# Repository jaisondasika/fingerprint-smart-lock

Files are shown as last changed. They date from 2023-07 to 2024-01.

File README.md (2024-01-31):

# Fingerprint Smart Lock

An Arduino based smart lock that also controls a LED strip. The LEDs react to you based on how close you are to the door and play a fun animation when unlocked! This also features anti-theft mode, which alarms if the door is broken open, and anti-pick mode, which vibrates the servo to make lockpicking impossible when detected!



This project has been tested on both the [TeensyLC](https://www.pjrc.com/store/teensylc.html) and [SeeduinoXIAO](https://www.seeedstudio.com/Seeeduino-XIAO-Arduino-Microcontroller-SAMD21-Cortex-M0+-p-4426.html) microcontrollers. The TeensyLC has been in limited supply due to the chip shortage, so I added functionality for the SeeeduinoXIAO board since they are readily available and are a suitable alternative. 

## Parts

[SeeeduinoXIAO](https://www.amazon.com/dp/B08CN5YSQF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)

[Fingerprint Scanner](https://www.amazon.com/%25E3%2580%2590%25F0%259D%2590%258C%25F0%259D%2590%259E%25F0%259D%2590%25AB%25F0%259D%2590%25AB%25F0%259D%2592%259A-%25F0%259D%2590%2582%25F0%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)

[Servo](https://www.amazon.com/Hosyond-Helicopter-Airplane-Control-Compatible/dp/B09V5BR7J5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)

[LED Strip](https://www.amazon.com/BTF-LIGHTING-Flexible-Individually-Addressable-Non-waterproof/dp/B01CDTEJBG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)

[Lidar](https://www.amazon.com/Single-Point-Compatible-Rasppbarry-Communication-Interface/dp/B088NVX2L7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)

[Button](https://www.amazon.com/weideer-Momentary-Self-Reset-Pre-soldered-R13-507-5-X/dp/B08SQHRRDH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)

[Hall Effect Sensor](https://www.amazon.com/EPLZON-Effect-Magnetic-Detector-Arduino/dp/B09PG3PGH6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)

[Buzzer](https://www.amazon.com/Gikfun-Active-Magnetic-Continous-Arduino/dp/B01FVZQ6F6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)

[Power Supply](https://www.amazon.com/Henxlco-AC100-240V-Converter-Transformer-Light%25EF%25BC%258CCCTV/dp/B0BFLYDKKD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)

## Wiring Diagram
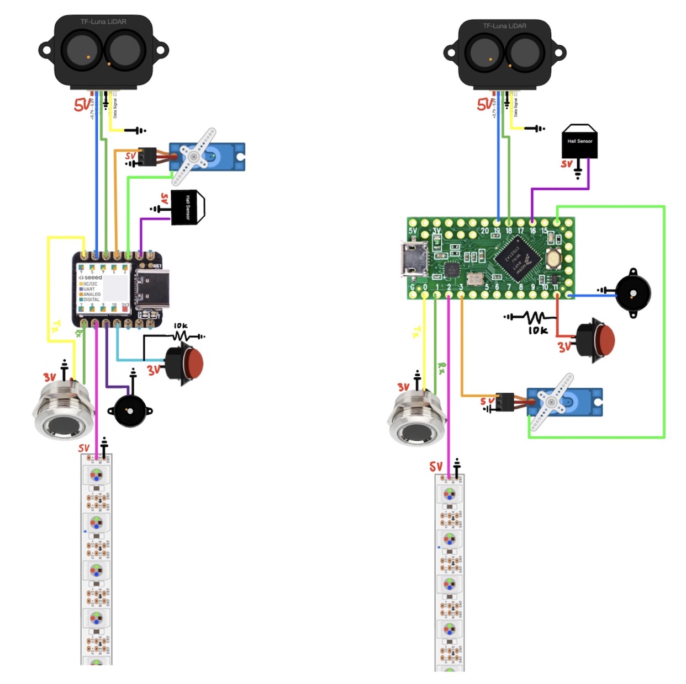
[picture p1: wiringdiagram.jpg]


## Other Info
In order to add fingerprints that unlock the door, you will need to upload the "enroll" sketch to the microcontroller and follow the prompts in the serial monitor. This sketch can be found under file > examples > Adafruit Fingerprint Sensor Library > enroll

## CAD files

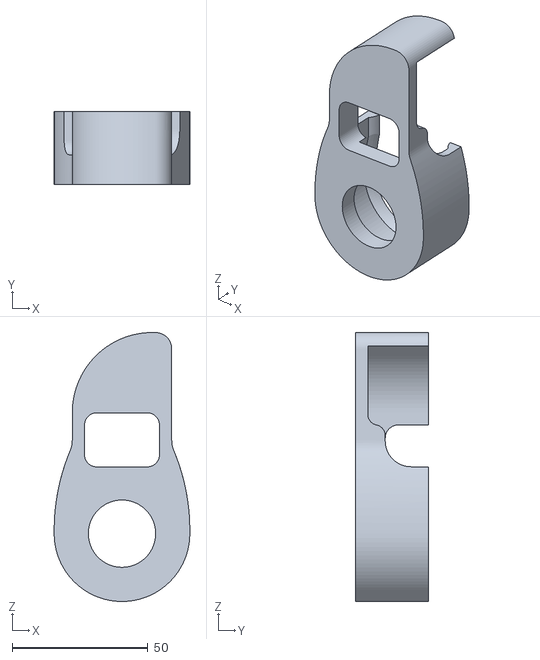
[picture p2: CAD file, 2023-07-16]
3D Files/STLs/Exterior Terminal.stl
50.0 x 27.0 x 99.1

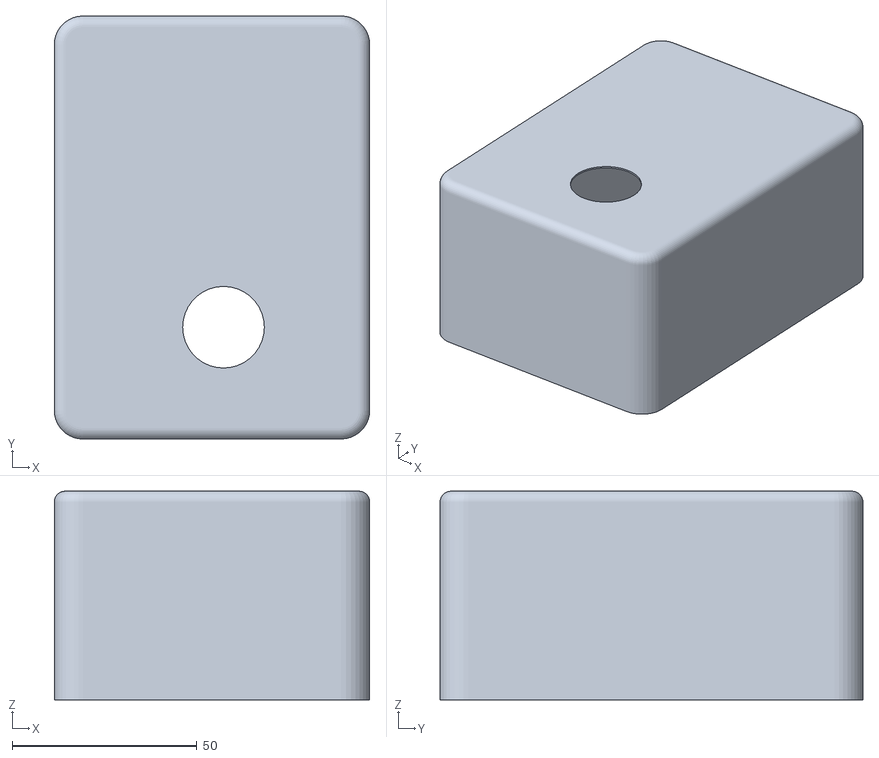
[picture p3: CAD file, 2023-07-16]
3D Files/STLs/Mount Cover.stl
85.4 x 114.5 x 56.5

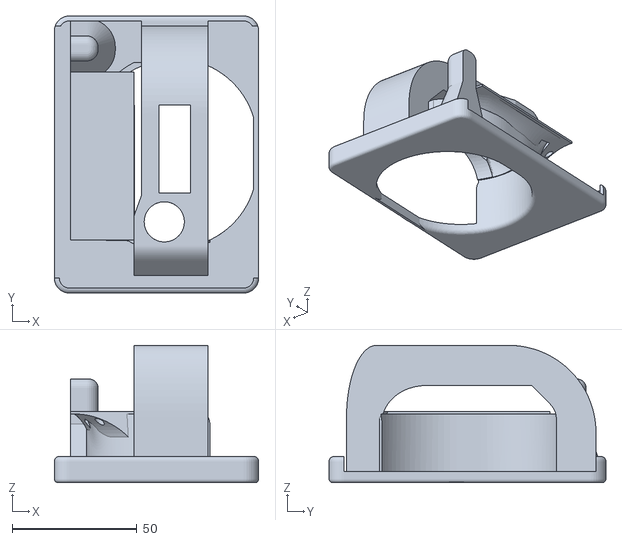
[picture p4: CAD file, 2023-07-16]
3D Files/STLs/Interior Mount.stl
81.9 x 111.0 x 55.0

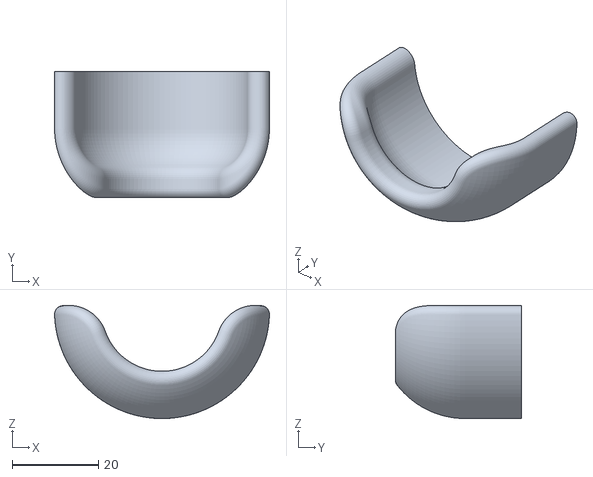
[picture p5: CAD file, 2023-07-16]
3D Files/STLs/Rain Cover.stl
50.0 x 29.4 x 26.3

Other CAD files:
3D Files/Fusion360 Files/Interior Mount.f3d
3D Files/Fusion360 Files/Rain Cover.f3d

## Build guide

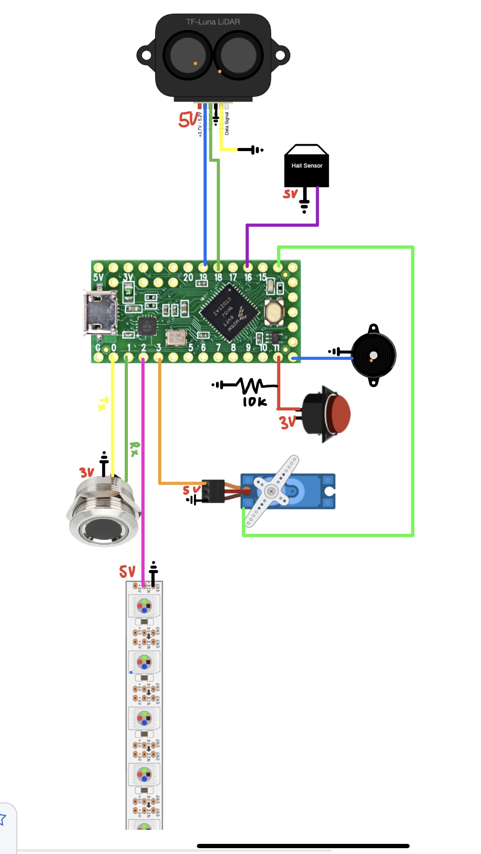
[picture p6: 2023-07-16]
For TeensyLC Microcontroller/WiringDiagramTeensyLC.jpg

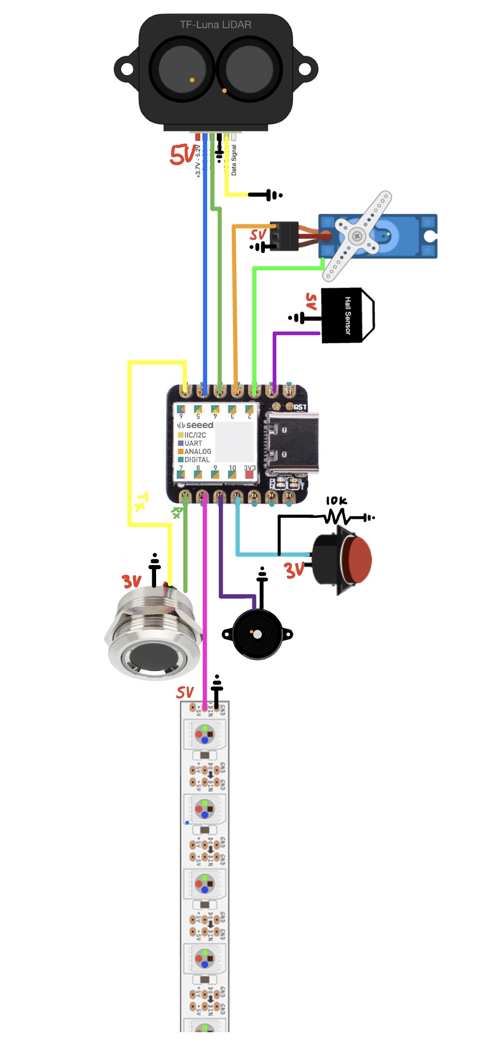
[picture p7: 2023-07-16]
For SeeduinoXIAO Microcontroller/WiringDiagramSeeeduinoXIAO.jpg

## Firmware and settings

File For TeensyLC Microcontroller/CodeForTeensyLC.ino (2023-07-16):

/********************************************************************

     --------- FINGERPRINT DOOR UNLOCK + LED LIGHTS ---------

               This script is designed to run on the
                        Teency LC board

                    Code written by Jaison Dasika

          Watch the full youtube video for the wiring diagram 
                  and details explaining the setup

 *********************************************************************/

#include <Adafruit_Fingerprint.h>
#include <FastLED.h>
#include <Servo.h>
#include <Wire.h>
#include <TFLI2C.h>

//Define pin locations on the board
#define SERVO_ENCODER_PIN A0
#define HALL_PIN A2
#define BUTTON_PIN 11
#define BUZZER_PIN 12
#define LED_PIN 2
#define SERVO_PIN 3

//Define attributes
#define NUM_LEDS 300
#define BRIGHTNESS 20            //Brigtness of LED strip
#define TIME_DELAY 2200           //how long till the door automatically locks
#define DOOR_CLOSED_HALL_VAL 850  //Reading for the hall sensor when the door closes
#define UNLOCKED_SERVO_VAL 0      //Servo value to unlock the door
#define LOCKED_SERVO_VAL 90       //Servo value to lock the door
#define DEADBOLT_OPENED_VAL 320  //Encoder unlocked value
#define DEADBOLT_LOCKED_VAL 383  //Encoder locked value


//Define variables with the least amount of memory needed for their respective tasks
unsigned long previousMillis, currentMillis = 0;
bool doorIsLocked = true, deadboltIsJammed = false, ledRingBreathing = false;
float hue = 1, hue2 = 1;
int16_t bulbs2light, tfDist, tfAddr = TFL_DEF_ADR;  //Lidar address


#if (defined(__AVR__) || defined(ESP8266)) && !defined(__AVR_ATmega2560__)
// For UNO and others without hardware serial, use software serial...
// pin #2 is IN from sensor (GREEN wire)
// pin #3 is OUT from arduino  (WHITE wire)
// Set up the serial port to use softwareserial..
SoftwareSerial mySerial(2, 3);
#else
// On Leonardo/M0/etc, others with hardware serial, use hardware serial!
// #0 is green wire, #1 is white
#define mySerial Serial1
#endif

//Initialize objec
CRGB leds[NUM_LEDS];
Servo servo;
TFLI2C tflI2C;  //TFmini LiDAR sensor
Adafruit_Fingerprint finger = Adafruit_Fingerprint(&mySerial);

//Runs only once on startup
void setup() {
  delay(400);
  LEDS.addLeds<WS2812, LED_PIN, GRB>(leds, NUM_LEDS);
  LEDS.setBrightness(BRIGHTNESS);
  pinMode(BUZZER_PIN, OUTPUT);
  pinMode(BUTTON_PIN, INPUT);
  Serial.begin(115200);
  delay(10);
  Wire.begin();  // Initalize Wire library
  tone(BUZZER_PIN, 444);
  delay(80);
  noTone(BUZZER_PIN);
  delay(10);
  Serial.println(F("\n\nAdafruit finger detect test"));
  // set the data rate for the sensor serial port
  //finger.begin(57600); //alternate baud rate
  finger.begin(58824);
  delay(10);
  if (finger.verifyPassword()) {
    Serial.println("Found fingerprint sensor!");
  } else {
    Serial.println("Did not find fingerprint sensor :(");
    while (1) {
      delay(1);
    }
  }

  Serial.println(F("Reading sensor parameters"));
  finger.getParameters();
  Serial.print(F("Status: 0x"));
  Serial.println(finger.status_reg, HEX);
  Serial.print(F("Sys ID: 0x"));
  Serial.println(finger.system_id, HEX);
  Serial.print(F("Capacity: "));
  Serial.println(finger.capacity);
  Serial.print(F("Security level: "));
  Serial.println(finger.security_level);
  Serial.print(F("Device address: "));
  Serial.println(finger.device_addr, HEX);
  Serial.print(F("Packet len: "));
  Serial.println(finger.packet_len);
  Serial.print(F("Baud rate: "));
  Serial.println(finger.baud_rate);
  finger.getTemplateCount();

  if (finger.templateCount == 0) {
    Serial.print(F("Sensor doesn't contain any fingerprint data. Please run the 'enroll' example."));
  } else {
    Serial.println(F("Waiting for valid finger..."));
    Serial.print(F("Sensor contains "));
    Serial.print(finger.templateCount);
    Serial.println(F(" templates"));
  }
}

//This function loops repeatidly
void loop() {
  delay(3);
  lidarLight();        //Makes the lights follow your position to the door
  jitterMode();
  getFingerprintID();  //Poll for fingerprint
  //burglerMode();
  currentMillis = millis();
  //When button is pressed, unlock the door
  if (digitalRead(BUTTON_PIN) == 1) {
    delay(250);
    unlockDoor();
    holdDoorUnlocked();
  }

  //When door is closed, lock the door
  if (doorIsLocked == false && analogRead(HALL_PIN) >= DOOR_CLOSED_HALL_VAL
      && currentMillis - previousMillis >= TIME_DELAY) {
    previousMillis = currentMillis;
    delay(100);
    lockDoor();
  }
}

//Unlocks the door
void unlockDoor() {
  doorIsLocked = false;
  previousMillis = currentMillis;
  servo.attach(SERVO_PIN);
  servo.write(UNLOCKED_SERVO_VAL);
  uint8_t buzzerDelay = 90;
  tone(BUZZER_PIN, 698.46);
  delay(buzzerDelay);
  tone(BUZZER_PIN, 880.00);
  delay(buzzerDelay);
  tone(BUZZER_PIN, 1046.50);
  delay(buzzerDelay);
  tone(BUZZER_PIN, 1396.91);
  delay(buzzerDelay);
  noTone(BUZZER_PIN);
  delay(200);
  servo.detach();
}

//Locks the door
void lockDoor() {
  doorIsLocked = true;
  finger.LEDcontrol(FINGERPRINT_LED_FLASHING, 25, FINGERPRINT_LED_BLUE, 10);
  uint8_t buzzerDelay = 110;
  tone(BUZZER_PIN, 1396.91);
  delay(buzzerDelay);
  tone(BUZZER_PIN, 1046.50);
  delay(buzzerDelay);
  tone(BUZZER_PIN, 880.00);
  delay(buzzerDelay);
  tone(BUZZER_PIN, 698.46);
  noTone(BUZZER_PIN);

  //Slows the servo as it locks to prevent wear on servo in case of jam
  servo.attach(SERVO_PIN);
  uint16_t tempLockVal;
  while (servo.read() != LOCKED_SERVO_VAL) {
    tempLockVal = tempLockVal + 1;
    servo.writeMicroseconds(tempLockVal);
    delay(1);
  }
  servo.detach();
  delay(100);

  //test to see if deadbolt got jammed
  if ((analogRead(SERVO_ENCODER_PIN) < DEADBOLT_LOCKED_VAL)) {
    deadboltIsJammed = true;
    deadboltJammed();
  } else {
    deadboltIsJammed = false;
  }
}

//Open the deadbolt and alert if the deadbolt is jammed
void deadboltJammed() {
  servo.attach(SERVO_PIN);
  servo.write(UNLOCKED_SERVO_VAL);
  alert(2);
  delay(10);
  servo.detach();
  blinkLEDS("ORANGE");
}

//Vibrates the servo and resists if someone is trying to pick the lock
void jitterMode() {
  if (analogRead(SERVO_ENCODER_PIN) < DEADBOLT_LOCKED_VAL && doorIsLocked == true && deadboltIsJammed == false) {
    alert(2);
    servo.attach(SERVO_PIN);
    servo.write(LOCKED_SERVO_VAL);
    alert(2);
    servo.detach();
    Serial.print(F("Jitter mode activated!!"));
  }
}

//Alarms if the door has an unauthorized open
void burglerMode() {
  if (doorIsLocked && analogRead(HALL_PIN) < DOOR_CLOSED_HALL_VAL) {
    alert(1);
    blinkLEDS("RED");
    Serial.print(F("Burgler mode activated!!"));
  }
}

//quickly flashes all LEDS with a specified color
void blinkLEDS(String s) {
  if (s.equals("RED")) {
    fill_solid(leds, NUM_LEDS, CRGB::Red);
    FastLED.show();
  } else if (s.equals("ORANGE")) {
    fill_solid(leds, NUM_LEDS, CRGB::Orange);
    FastLED.show();
  } else if (s.equals("GREEN")) {
    fill_solid(leds, NUM_LEDS, CRGB::Green);
    FastLED.show();
  }
  delay(50);
  FastLED.clear();
  FastLED.show();
}

//makes a fast beeping noise
void alert(uint8_t numBeeps) {
  for (uint8_t i = 0; i < numBeeps; i++) {
    tone(BUZZER_PIN, 329.625);
    delay(50);
    noTone(BUZZER_PIN);
    delay(20);
  }
}

//Fingerprint is not in the database
void noFingerMatch() {
  tone(BUZZER_PIN, 400);
  blinkLEDS("RED");
  finger.LEDcontrol(FINGERPRINT_LED_FLASHING, 4, FINGERPRINT_LED_RED, 16);
  delay(80);
  noTone(BUZZER_PIN);
  FastLED.clear();
  FastLED.show();
  //finger.LEDcontrol(FINGERPRINT_LED_GRADUAL_OFF, 100, FINGERPRINT_LED_RED);
}

//Read the fingerprint (credit to Adafruit)
uint8_t getFingerprintID() {
  uint8_t p = finger.getImage();
  switch (p) {
    case FINGERPRINT_OK:
      Serial.println(F("Image taken"));
      break;
    case FINGERPRINT_NOFINGER:
      Serial.println(F("No finger detected"));
      return p;
    case FINGERPRINT_PACKETRECIEVEERR:
      Serial.println(F("Communication error"));
      return p;
    case FINGERPRINT_IMAGEFAIL:
      Serial.println(F("Imaging error"));
      return p;
    default:
      Serial.println(F("Unknown error"));
      return p;
  }

  // OK success!

  p = finger.image2Tz();
  switch (p) {
    case FINGERPRINT_OK:
      Serial.println(F("Image converted"));
      break;
    case FINGERPRINT_IMAGEMESS:
      Serial.println(F("Image too messy"));
      return p;
    case FINGERPRINT_PACKETRECIEVEERR:
      Serial.println(F("Communication error"));
      return p;
    case FINGERPRINT_FEATUREFAIL:
      Serial.println(F("Could not find fingerprint features"));
      return p;
    case FINGERPRINT_INVALIDIMAGE:
      Serial.println(F("Could not find fingerprint features"));
      return p;
    default:
      Serial.println(F("Unknown error"));
      return p;
  }

  // OK converted!
  p = finger.fingerSearch();
  if (p == FINGERPRINT_OK) {
    Serial.println(F("Found a print match!"));
    finger.LEDcontrol(FINGERPRINT_LED_BLUE, 8, FINGERPRINT_LED_OFF, 12);
    unlockDoor();
    blinkLEDS("GREEN");
    theaterChaseRainbow(7);
  } else if (p == FINGERPRINT_PACKETRECIEVEERR) {
    Serial.println(F("Communication error"));
    return p;
  } else if (p == FINGERPRINT_NOTFOUND) {
    Serial.println(F("Did not find a match"));
    noFingerMatch();
    return p;
  } else {
    Serial.println(F("Unknown error"));
    return p;
  }

  // found a match!
  Serial.print(F("Found ID #"));
  Serial.print(finger.fingerID);
  Serial.print(F(" with confidence of "));
  Serial.println(finger.confidence);
  return finger.fingerID;
}

//Returns -1 if failed, otherwise returns ID # (Adafruit)
int getFingerprintIDez() {
  uint8_t p = finger.getImage();
  if (p != FINGERPRINT_OK) return -1;

  p = finger.image2Tz();
  if (p != FINGERPRINT_OK) return -1;

  p = finger.fingerFastSearch();
  if (p != FINGERPRINT_OK) return -1;

  // found a match!
  Serial.print(F("Found ID #"));
  Serial.print(finger.fingerID);
  Serial.print(F(" with confidence of "));
  Serial.println(finger.confidence);
  return finger.fingerID;
}

//Make the lights react to the LiDAR distance
void lidarLight() {
  if (tflI2C.getData(tfDist, tfAddr)) {
    if (ledRingBreathing == false) {
      ledRingBreathing = true;
      finger.LEDcontrol(FINGERPRINT_LED_BREATHING, 88, FINGERPRINT_LED_PURPLE);
    }
    delay(1);
    FastLED.clear();
    uint16_t bulbs2light = map(tfDist, 10, 600, 150, 0);

    if (bulbs2light < 0) bulbs2light = 0;
    if (bulbs2light > 147) {
      hue += 1.2;
      hue2 = hue;
    }

    for (uint16_t i = 0; i <= bulbs2light; i++) {
      leds[i] = CHSV(hue2 + i * 0.7, 150, 255);
      leds[NUM_LEDS - i] = CHSV(hue2 + i * 0.7, 150, 255);
    }
    FastLED.show();
  } else {
    //if nothing in front of LiDAR or sensor malfunctions, clear LEDs
    FastLED.clear();
    FastLED.show();
    if (ledRingBreathing == true) {
      ledRingBreathing = false;
      finger.LEDcontrol(false);
      finger.LEDcontrol(FINGERPRINT_LED_OFF, 0, FINGERPRINT_LED_OFF);
    }
  }
}

//Helper method for theaterChaseRainbow()
byte *Wheel(byte WheelPos) {
  static byte c[3];
  WheelPos = 255 - WheelPos;
  if (WheelPos < 85) {
    c[0] = WheelPos * 3;
    c[1] = 255 - WheelPos * 3;
    c[2] = 0;
  } else if (WheelPos < 170) {
    WheelPos -= 85;
    c[0] = 255 - WheelPos * 3;
    c[1] = 0;
    c[2] = WheelPos * 3;
  } else {
    WheelPos -= 170;
    c[0] = 0;
    c[1] = WheelPos * 3;
    c[2] = 255 - WheelPos * 3;
  }
  return c;
}

//Rainbow effect when correct finger is read
void theaterChaseRainbow(int SpeedDelay) {
  byte *c;
  for (int j = 0; j < 156; j++) {  // cycle all 256 colors in the wheel
    for (int q = 0; q < 7; q++) {
      for (int i = 0; i < NUM_LEDS; i = i + 7) {
        c = Wheel((i + j) % 255);
        leds[i + q] = CRGB(*c, *(c + 1), *(c + 2));
      }
      FastLED.show();
      delay(SpeedDelay);
      for (int i = 0; i < NUM_LEDS; i++) {
        leds[i + q] = CRGB(0, 0, 0);
      }
      //Stop the animation when the door opens
      if (analogRead(HALL_PIN) < DOOR_CLOSED_HALL_VAL) {
        break;
      }
    }
  }
}

//When the button is held down, the door will stay unlocked until the button is pressed
void holdDoorUnlocked() {
  if (digitalRead(BUTTON_PIN) == 1) {
    delay(140);
    int buzzerDelay = 220;
    tone(BUZZER_PIN, 349.23);
    delay(buzzerDelay);
    tone(BUZZER_PIN, 523.25);
    delay(buzzerDelay);
    tone(BUZZER_PIN, 587.23);
    delay(buzzerDelay);
    tone(BUZZER_PIN, 659.25);
    delay(buzzerDelay);
    tone(BUZZER_PIN, 698.46);
    delay(buzzerDelay);
    noTone(BUZZER_PIN);
    FastLED.clear();
    FastLED.show();

    //hold door unlocked until button is pressed again
    while (true) {
      delay(1);
      lidarLight();
      if (digitalRead(BUTTON_PIN) == 1) {
        break;
        delay(30);
      }
    }
  }
}
